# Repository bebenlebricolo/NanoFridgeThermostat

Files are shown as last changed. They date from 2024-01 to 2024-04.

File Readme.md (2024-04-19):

# Readme's Index
- [Readme's Index](#readmes-index)
- [Nano Fridge Thermostat](#nano-fridge-thermostat)
- [Nano Thermostat V2](#nano-thermostat-v2)
- [Known issues on V2 board](#known-issues-on-v2-board)
- [Git submodules setup (Optional, used for hardware development)](#git-submodules-setup-optional-used-for-hardware-development)
  - [Screenshots (view taken before manufacturing)](#screenshots-view-taken-before-manufacturing)
- [Hardware design](#hardware-design)
  - [Simulations](#simulations)
  - [Electronic design](#electronic-design)
    - [Mother board](#mother-board)
    - [Daughter board (AC power board)](#daughter-board-ac-power-board)
  - [Tools](#tools)
    - [Thermistor data source files generator](#thermistor-data-source-files-generator)
    - [Resistor bridge calculator](#resistor-bridge-calculator)
- [Tests](#tests)
  - [Building the tests](#building-the-tests)
  - [Tests dependencies](#tests-dependencies)
- [Acknowledgment](#acknowledgment)

# Nano Fridge Thermostat
Welcome to the Nano Fridge project !
This project started up because my fridge thermostat was dying (actually it was pretty dead and noticed the fridge was not cooling anymore) and I needed to find something very quickly in order to keep it running a bit longer.
It's aimed at replacing the cheap (but very reliable) thermomechanical switch that's used in most low-end fridges.

The very first revision operated on an Arduino Nano and used regular relays to perform its task.
It was essentially an Open-Loop system, running the compressor for 1 hour, and letting it rest for 2 hours.
This Open Loop process works fine but does not take into account the internal temperature of the fridge.
Hence, the actual temperature was oscillating a lot between 2 or 3°C and 6 to 8°C, depending on how many times we would open it.

The first revision of this project can be found on tag V1.0.0

# Nano Thermostat V2
A newer revision of the thermostat is currently in the works and several small improvements will be provided :
* Safe compressor start up procedure
* Thermistor support (NTC)
* Closed-Loop control algorithms (very simple hysteresis at first)
* Screen and buttons to monitor and setup the fridge parameters from outside the fridge.

More details can be found in the [NanoThermostat-V2](NanoThermostat-V2) folder.

A custom PCB was designed for this board (as the electrical design became more and more crowded with components and functionalities).
It can be found under the [Hardware](Hardware/) folder, and I used KiCAD 7 to design the boards.

# Known issues on V2 board
This applies to the git tag **hardware-V2.0.0-to-fab**
* Swapped buttons (silkscreen is "right" but - button actually is on the right and + button is on the left)
  * We only need to rewire them correctly :smile:

# Git submodules setup (Optional, used for hardware development)
In order for this project to be usable (especially to get all the footprints here), you'll need to initialise and download git submodules.
This can be done like so :
```bash
git submodule update --init --recursive
```

## Screenshots (view taken before manufacturing)
<figure>
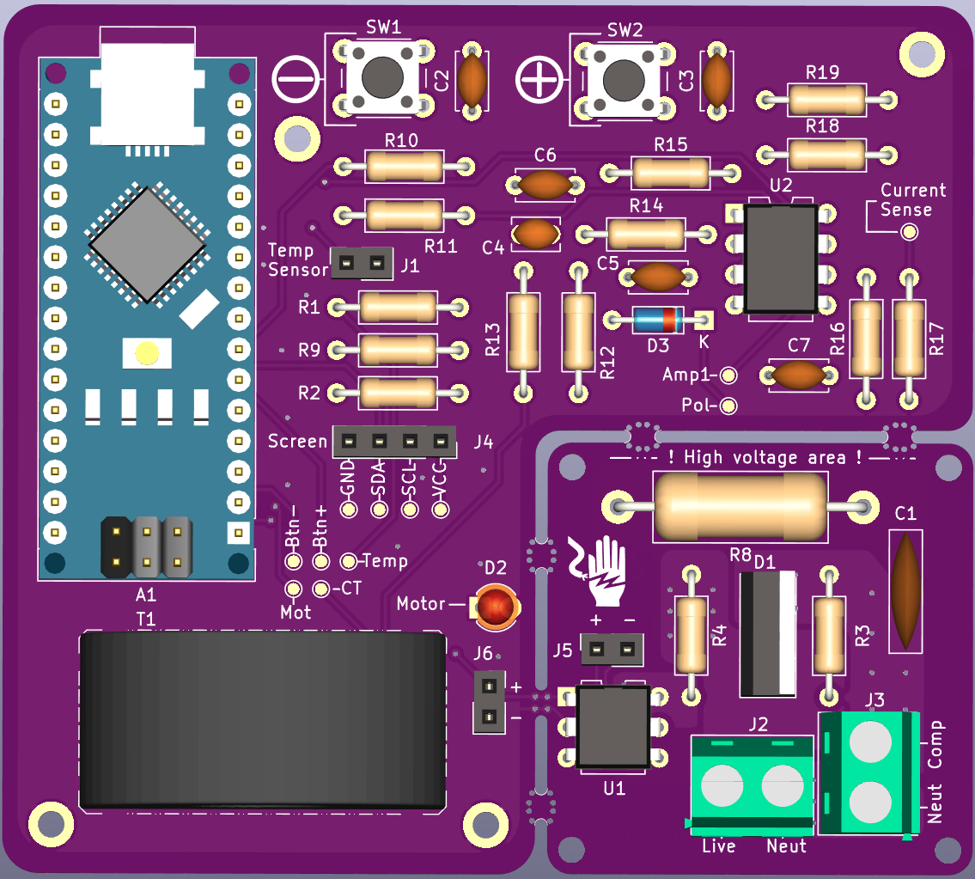
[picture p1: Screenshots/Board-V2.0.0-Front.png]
Board V2.0.0 Front
    
    <figcaption>Board V2.0.0, Front</figcaption>
</figure>
<figure>
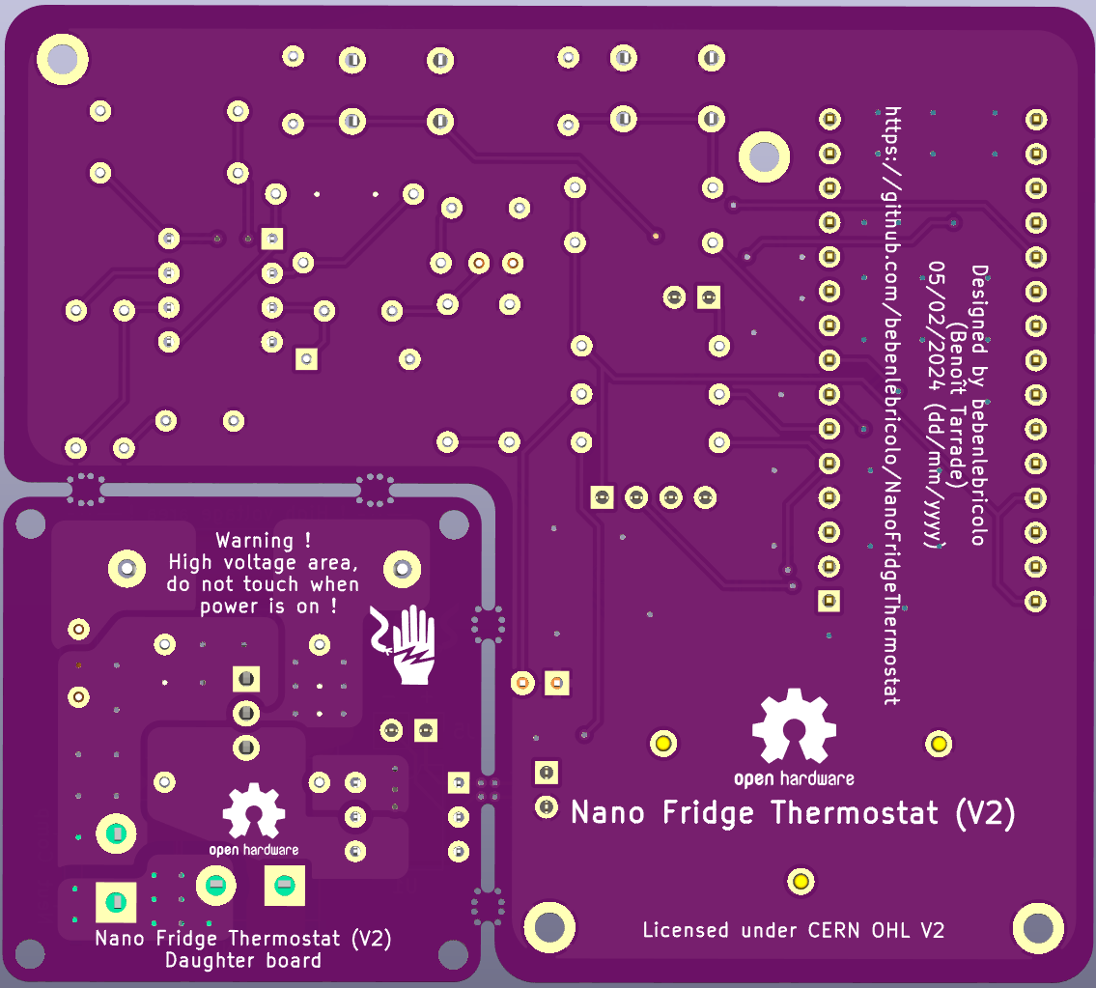
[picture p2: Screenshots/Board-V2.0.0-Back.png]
Board V2.0.0 Back
    
    <figcaption>Board V2.0.0, Back</figcaption>
</figure>
<figure>
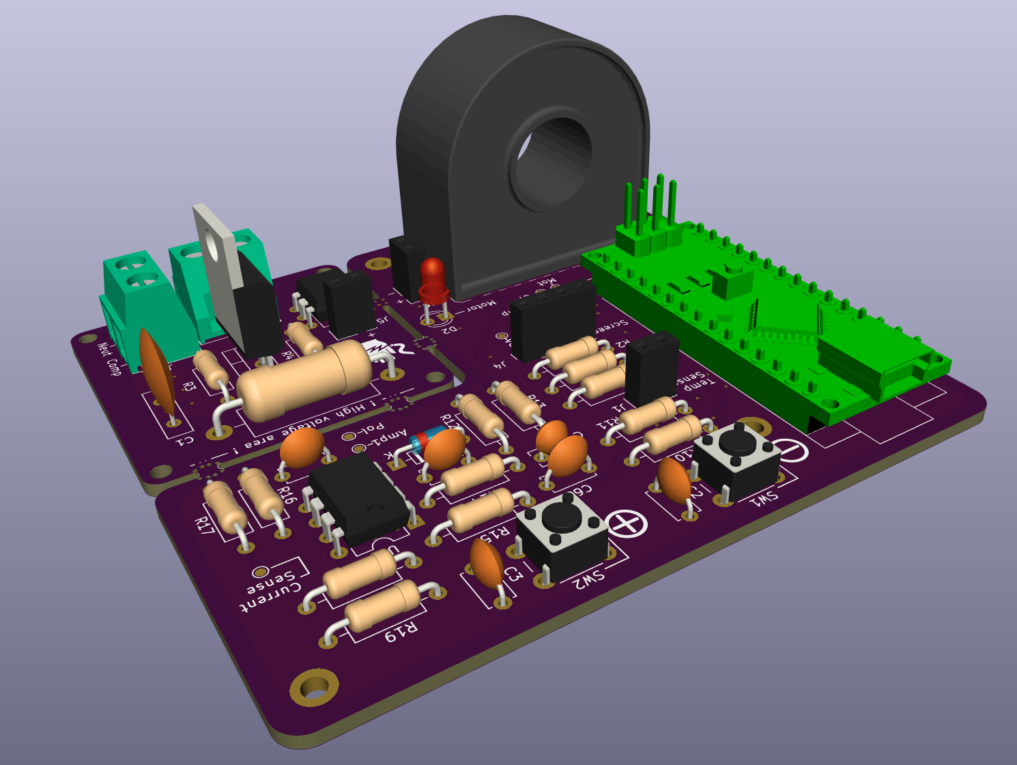
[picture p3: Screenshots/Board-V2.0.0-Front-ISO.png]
Board V2.0.0 Iso
    
    <figcaption>Board V2.0.0, Iso</figcaption>
</figure>

# Hardware design
As said, these boards were designed with KiCAD 7 which is a free open source software.
You'll need a copy of it installed on your machine in order to open hardware files.

## Simulations
Some simulations were used in this project as well and can be found under [Hardware/Simulations](Hardware/Simulations/).
Those simulations were performed with the very good LTSpice tool, released publicly and for free by Linear Technologies.
Despite not being open source per se, this tool can be installed on Linux as well using Wine wrappers.

## Electronic design
This new board (V2.0.0) includes 2 boards attached by small tabs. One of them carries the signal that goes to the triac driver. They are designed to be manually snapped, as the daughter board (the smaller one) needs to be galvanically isolated from the mother board.

### Mother board
The mother board carries and Arduino Nano V3 and works with low voltages (5V).
Power is supplied via the Arduino's USB connector and the system is designed to consume very little power (less than 100mA, most probably around 30/50 mA)

It's main features are :
* AC current sense : used to sense the current that goes into the fridge compressor
  * Used mainly as a security feature as it allows to detect conditions where the fridge compressor is stalled (when power cycling the compressor in time interval shorter than around 5 minutes, cooling fluids prevent the motor to start, hence pulling a large amount of current for an extended period of time, causing coil overheating).
  * This security feature is mostly intended to cover the cases where general power is cut off and quickly returns to normal. Microcontroller will reboot under such conditions and as there is no embedded RTC, there is no means to tell how long the power cut was, potentially causing the board to trigger the motor again. Monitoring pulled current can help detect such conditions and allow to delay compressor operation enough to get back under normal working conditions.
* Fridge compressor control using zero crossing detection (triac driver + triac)
* Fridge temperature sensing using NTC thermistor.
* I2C connector so that we can extend the board functionalities by plugging in a LCD screen.
* 2 buttons to control the boards behavior (forecasted roles were + and - buttons to lower or raise set point temperature, and reset internal memory.)

> Note : this board can easily be leveraged to control other small AC appliances ; as long as the triac is adapted to the target's power requirements. One will need to also adapt the 2 stages amplifier for the current sensing return loop in order to adapt to larger currents (and potentially adapt the Current Transformer as well).

### Daughter board (AC power board)
This small board can be detached from the mother board using the provided "mouse bites".
Usually, this board will be placed close to the compressor, in a well ventilated area to accommodate for the triac's heat under working conditions, whereas the mother board will be placed further.

It carries the triac driver (which is optoisolated) and the triac itself ([FT0814MH](https://docs.rs-online.com/2b24/0900766b8150e268.pdf), which is actually a Fagor specific item, specially crafted for fridges).
It's main role is then to switch the power on and off of the fridge's compressor.

## Tools
### Thermistor data source files generator
This repository embeds a small python ([thermistor_generator.py](Tools/thermistor_generator.py)) script whose purpose is to generate C source files for a given thermistor. It uses the basic parameters for a NTC thermistor :
* R0 : base resistance of the thermistor, at room temperature (usually, 25°Celsius)
* Beta constant : temperature constant, rated in Kelvin, for this thermistor
* name of the generated source files

It generates the default profile for an NTC thermistor, which needs to be compiled in the project in order to be used.
It's used through the small [thermistor.h](NanoThermostat-V2/thermistor.h) and [thermistor.c](NanoThermostat-V2/thermistor.c) module as the reference table for temperature reading.

Usage :
```bash
python thermistor_generator.py 100 3950 thermistor_ntc_100k_3950K --min -24 --max 25 --count 25
# 1 - Generating thermistor data
# 2 - Generating header file
# 3 - Generating source file
```
This generates files in the [Generated](Generated) folder.

### Resistor bridge calculator
This small python script ([resistor_bridge.py](Tools/resistor_bridge.py)) lets you calculate the ideal value for the upper resistor for a resistor bridge where a NTC thermistor is used as the lower part.
It finds the ideal value that maximizes the output voltage swing amplitude, based on the thermistor used temperature/resistance range.
Boosting the output voltage swing amplitude means that the Arduino's ADC will get a better resolution, hence better result as the usable voltage range is bigger.

Usage :
```bash
python resistor_bridge.py 100 1024
Ideal resistance value for R should be : 320.0
The unit (Ohms, KOhms, MOhms) is the same as input data
```

# Tests
This project embeds some tests projects.
Those tests are checking that the logic works on a desktop environment prior to be compiled and embedded on a tiny MCU.

## Building the tests
Runs with CMake :
```bash
cmake NanoThermostat-V2 -Bbuild
cd build/
make -j
```

## Tests dependencies
Googletest framework is used as a test framework and needs to be installed beforehand.
This is automatically done on Windows platforms (latest build zip is downloaded by CMake itself).
On Linux, a system-wide installation works very well :
```bash
pacman -S gtest # arch linux
apt-get install libgtest # Ubuntu/debian
```

# Acknowledgment
This repository uses open source software, tools and assets publicly available.

* [KiCAD](https://www.kicad.org/) 7.X
  * Used to develop the hardware/electronic design
* [FreeCAD](https://www.freecad.org/) 0.2XXX
* Used to develop the hardware/mechanical design
* [LTSpiceXVII](https://www.analog.com/en/resources/design-tools-and-calculators/ltspice-simulator.html) -> Available on Windows and Linux (via Wine, check your linux distribution packages).
  * Used to develop electronic simulations
* [kicad-lib-arduino](https://github.com/g200kg/kicad-lib-arduino)
  * Used as part of the hardware design process (mainly the Arduino Nano V3 3D model)
  * [Creative Common License : CC0 1.0 Universal](https://github.com/g200kg/kicad-lib-arduino/blob/main/LICENSE)
* [Panelization.pretty](https://github.com/madworm/Panelization.pretty)
  * Used as part of the hardware design process (used the mouse bites footprints)
  * No license for now (Feb 2024) ?
* [googletest](https://github.com/google/googletest)
  * Google's C/C++ unit testing framework
  * [BSD-3-Clause license](https://github.com/google/googletest/blob/main/LICENSE)

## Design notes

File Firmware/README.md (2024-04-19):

# Index
- [Index](#index)
- [NanoFridgeThermostat V2](#nanofridgethermostat-v2)
- [Hardware specs (first iteration)](#hardware-specs-first-iteration)
- [Safety features](#safety-features)
    - [Automatic rerun protection](#automatic-rerun-protection)
    - [Safe boot up sequence](#safe-boot-up-sequence)
    - [Temperature trigger Hysteresis (No PID)](#temperature-trigger-hysteresis-no-pid)
- [Roadmap](#roadmap)
  - [V2.0](#v20)
  - [V2.1](#v21)
  - [V2.2](#v22)
  - [V3 and Onwards](#v3-and-onwards)

# NanoFridgeThermostat V2
Off-the-shelf fridge thermostat using an ArduinoNano to replace a broken fridge thermomechanical thermostat.

This project was born with the sole purpose of repairing a dying fridge whose thermostat was completely dead.
The idea is first to provide a very basic cooling support, with a simple on/off cycle that can be programmed using on seconds and off seconds.

# Hardware specs (first iteration)
* Solid state switching circuitry
  * Optoisolated triac driver circuit (MOC3042 -> withstands 400V peak)
  * 600V / 8A RMS Triac (FT0814MH TU) -> TO220 package
* NTC Thermistor [amazon link](https://www.amazon.fr/gp/product/B07CQT5S7Y/ref=ppx_yo_dt_b_asin_title_o00_s00?ie=UTF8&psc=1)
  * Advertised  as 100k @ 25°C
  * Upper bridge resistor of 330kOhms gives the maximum output voltage swing from the divider bridge configuration (see [Thermistor spreadsheet](Thermistor%20values.ods) for a more detailed view).
* Phone USB charger (5V), 230V AC -> 5V DC
  * Ideally this could be replaced by a standalone AC/DC converter in the system, but for now a simple phone charger bloc will do the trick.

# Safety features
### Automatic rerun protection
As fridges' thermodynamic cycle has some constraints, it's not possible to restart the motor right after a run for a short period of time.
My fridge is equipped with a fail-safe circuitry that breaks the circuit whenever the motor is stalled. A stalled motor draws much more current than expected in normal use, and it makes a thermal circuit breaker heat up, until the contact points separate ; the arm cools down and after some time springs back in normal position and closes the circuit again.

I don't want to rely only on this safety feature, so I'll add a software timer in between motor start up so that I'm sure it's not started in a too short amount of time.

### Safe boot up sequence
When the system boots up, it'll wait for 5 seconds before starting normal operation.
This will allow for the user to enter the "learn" mode (with a long press on a button).
This mode will be used to reset internal memory and start characterising compressor motor again (monitoring current in "normal" operation).
This characterisation of the motor will be later used to detect stalled motor conditions even if the system's power goes off for a while and returns back in a short time.
Motor characterisation loop runs the compressor regardless of the frige's temperature in order to provide consistent results.

Then, normal operation will take over.
A long press on the same button allows to enter the learning mode again.
If the board was already in cooling mode at this time, it'll simply keep running the motor until the end of the learn process and reverts back to operation without interfering with the current operation.

### Temperature trigger Hysteresis (No PID)
I'll use an Hysteresis instead of a PID trigger for now and keep track of the ON/OFF cycles, avoiding to start the motor too often.
The risk when starting the motor too often (as stated above) is to go into thermal runaway or to stress the motor and compressor too much with start up cycles.
This can be minimized by opening a window that relies on a hysteresis.
PID will do the trick as well, the hysteresis function is more than sufficient to keep hovering around the average temperature whilst keeping the startup cycles at a minimum.

# Roadmap
## V2.0
* Fixed 4.0 °C degrees temperature target, no UI (no screen, no buttons, no interactions)
* Fixed hysteresis window (+- 2°C around the set point)
* Start up protection delay (as mentioned in [Automatic rerun protection](#automatic-rerun-protection))

## V2.1
* Flexible target temperature (dynamically adjustable). Requires some level of human interaction
  * I2C Oled screen with buttons
    * "+" and "-" buttons
    * One "Ok" button

## V2.2
* Probably a PID

## V3 and Onwards
* Additional light control (LEDs)
* Fans to circulate the air within the fridge
* Custom PCB that hosts all of the features described above

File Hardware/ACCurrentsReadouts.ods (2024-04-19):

Current (ma)
-160
-160
-140
-110
-80
-20
30
70
110
140
160
160
140
120
80
30
-30
-70
-110
-140
 | Gain
 | 22
Voltage (mv) | Calculated current | Max | Min | Peak-Peak | RMS
293 | 133 | 194,090909090909 | -191,818181818182 | 385,909090909091 | 136,439467551677
365 | 166
427 | 194
413 | 188
374 | 170
302 | 137
206 | 94
62 | 28
-72 | -33
-192 | -87
-283 | -129
-379 | -172
-422 | -192
-418 | -190
-365 | -166
-307 | -140
-206 | -94
-77 | -35
77 | 35
182 | 83

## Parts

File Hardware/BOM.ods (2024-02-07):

Source:
Date: | lun. 05 févr. 2024 21:03:38
Tool: | Eeschema 7.0.10
Generator: | /usr/share/kicad/plugins/bom_csv_grouped_by_value.py
Component Count: | 57
Collated Components:
Item | Qty | Reference(s) | Value | Ref | LibPart | Footprint | Datasheet | DNP
1 | 1 | A1 | Arduino_Nano_v3.x | Arduino Nano V3 | MCU_Module:Arduino_Nano_v3.x | Module:Arduino_Nano | http://www.mouser.com/pdfdocs/Gravitech_Arduino_Nano3_0.pdf
2 | 1 | C1 | 10n / 500V+ AC | C322C103KBR5TA | Device:C | Capacitor_THT:C_Disc_D10.0mm_W2.5mm_P5.00mm | ~
3 | 5 | C2, C3, C5, C6, C7 | 1u | RCER71H105K2M1H03A | Device:C | Capacitor_THT:C_Disc_D4.7mm_W2.5mm_P5.00mm | ~
4 | 1 | C4 | 100n | K104K15X7RF53L2 | Device:C | Capacitor_THT:C_Disc_D3.8mm_W2.6mm_P2.50mm | https://docs.rs-online.com/b86a/0900766b816adfc3.pdf
5 | 1 | D1 | FT0814MH | FT0814MH | Device:Q_TRIAC_A1A2G | Package_TO_SOT_THT:TO-220-3_Vertical | https://docs.rs-online.com/2b24/0900766b8150e268.pdf
6 | 1 | D2 | LED | Any 3mm Led will do | Device:LED | LED_THT:LED_D3.0mm | ~
7 | 1 | D3 | D_Zener | BZX79-C5V1,113 | Device:D_Zener | Diode_THT:D_DO-35_SOD27_P7.62mm_Horizontal | ~
10 | 1 | J1 | ConnectorTriacDriver1 | Soldering pad (or 2.54 pitch header) | Connector:Conn_01x02_Socket | Connector_PinSocket_2.54mm:PinSocket_1x02_P2.54mm_Vertical | ~
11 | 1 | J5 | ConnectorTriacDriver2 | Soldering pad (or 2.54 pitch header) | Connector:Conn_01x02_Socket | Connector_PinSocket_2.54mm:PinSocket_1x02_P2.54mm_Vertical | ~
12 | 1 | J2 | Main_Connector | TE-282836-2 | Connector:Conn_01x02_Socket | TEConnectors:TE-282836-2-5.08mm | https://docs.rs-online.com/6880/0900766b8002dc8a.pdf
13 | 1 | J3 | CompressorMotor_Connector | TE-282836-2 | Connector:Conn_01x02_Socket | TEConnectors:TE-282836-2-5.08mm | https://docs.rs-online.com/6880/0900766b8002dc8a.pdf
14 | 1 | J4 | I2C_Conn | Soldering pad (or 2.54 pitch header) | Connector:Conn_01x04_Socket | Connector_PinSocket_2.54mm:PinSocket_1x04_P2.54mm_Vertical | ~
15 | 1 | R1 | 330K | 1/4 Watt through hole resistor (10%) | Device:R | Resistor_THT:R_Axial_DIN0207_L6.3mm_D2.5mm_P10.16mm_Horizontal | ~
16 | 3 | R2, R3, R9 | 330 | 1/4 Watt through hole resistor (10%) | Device:R | Resistor_THT:R_Axial_DIN0207_L6.3mm_D2.5mm_P10.16mm_Horizontal | ~
17 | 1 | R4 | 360 | 1/4 Watt through hole resistor (10%) | Device:R | Resistor_THT:R_Axial_DIN0207_L6.3mm_D2.5mm_P10.16mm_Horizontal | ~
18 | 1 | R8 | 330Ω / 1W | CFR200J330R | Device:R | Resistor_THT:R_Axial_DIN0614_L14.3mm_D5.7mm_P20.32mm_Horizontal | ~
19 | 2 | R10, R11 | 1k | 1/4 Watt through hole resistor (10%) | Device:R | Resistor_THT:R_Axial_DIN0207_L6.3mm_D2.5mm_P10.16mm_Horizontal | ~
20 | 1 | R12 | 22k | 1/4 Watt through hole resistor (10%) | Device:R | Resistor_THT:R_Axial_DIN0207_L6.3mm_D2.5mm_P10.16mm_Horizontal | ~
21 | 1 | R13 | 100 / 0,25W | 1/4 Watt through hole resistor (10%) | Device:R | Resistor_THT:R_Axial_DIN0207_L6.3mm_D2.5mm_P10.16mm_Horizontal | ~
22 | 1 | R14 | 2.2k | 1/4 Watt through hole resistor (10%) | Device:R | Resistor_THT:R_Axial_DIN0207_L6.3mm_D2.5mm_P10.16mm_Horizontal | ~
23 | 4 | R15, R17, R18, R19 | 100k | 1/4 Watt through hole resistor (10%) | Device:R | Resistor_THT:R_Axial_DIN0207_L6.3mm_D2.5mm_P10.16mm_Horizontal | ~
24 | 1 | R16 | 10k | 1/4 Watt through hole resistor (10%) | Device:R | Resistor_THT:R_Axial_DIN0207_L6.3mm_D2.5mm_P10.16mm_Horizontal | ~
25 | 2 | SW1, SW2 | SW_Push | Generic 6mm switch | Switch:SW_Push | Button_Switch_THT:SW_PUSH_6mm | ~
26 | 1 | T1 | CST1 | RS Pro : 124-3888 | CurrentTransformers:CT-RSPRO-1243888 | CurrentTransformer:CT-RSPRO-1243888 | https://docs.rs-online.com/3a8a/0900766b8169af75.pdf
27 | 1 | U1 | MOC3042M | MOC3042M (DIP-6 format) | Relay_SolidState:MOC3042M | Package_DIP:DIP-6_W7.62mm | https://www.onsemi.com/pub/Collateral/MOC3043M-D.pdf
28 | 1 | U2 | TL072 | TL072CD (DIP-8 format) | Amplifier_Operational:TL072 | Package_DIP:DIP-8_W7.62mm | http://www.ti.com/lit/ds/symlink/tl071.pdf

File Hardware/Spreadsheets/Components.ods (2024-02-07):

Snubber capacitor
Ref | Brand | Price (€) | Link | datasheet
C322C103KBR5TA | KEMET | 0,95 | https://fr.rs-online.com/web/p/condensateurs-ceramique-multicouches/9060654 | https://docs.rs-online.com/f300/0900766b81706bea.pdf
Snubber resistor
CFR200J330R | TE Connectivity | 0,12 | https://fr.rs-online.com/web/p/resistances-traversantes/0131996
Current transformer
124-3888 | RS-PRO | 1,99 | https://fr.rs-online.com/web/p/transformateurs-de-courant/1243888 | https://docs.rs-online.com/3a8a/0900766b8169af75.pdf
Low voltage cap
Ref | cap | voltage rating | Brand | Price (€) | Link | datasheet
K104K15X7RF53L2 | 100nF | 50V | Vishay | 0,119 | https://fr.rs-online.com/web/p/condensateurs-ceramique-multicouches/1816552 | https://docs.rs-online.com/b86a/0900766b816adfc3.pdf
RCER71H105K2M1H03A | 1uF | 50V | Murata | 0,355 | https://fr.rs-online.com/web/p/condensateurs-ceramique-multicouches/8410755 | https://docs.rs-online.com/dd62/0900766b8135e0d4.pdf
Zener 5.1V | Power | Price (€) | Link | datasheet
1N5338BG | 5W | 0,44 | https://fr.rs-online.com/web/p/diodes-zener/0463274 | https://docs.rs-online.com/b551/0900766b814f4429.pdf
BZX79-C5V1,113 | 500mW | 0,175 | https://fr.rs-online.com/web/p/diodes-zener/5443597 | https://docs.rs-online.com/9271/0900766b8073397e.pdf
Bornier 2 contacts
Ref | Brand | Price (€) | Link | datasheet
282836-2 | TE Connectivity | 1,26 | https://fr.rs-online.com/web/p/borniers-pour-circuits-imprimes/3617667 | https://docs.rs-online.com/6880/0900766b8002dc8a.pdf

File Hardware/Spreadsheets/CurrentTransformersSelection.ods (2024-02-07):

Current Transformers for 50/60Hz monitoring
Price (With taxes) € | Turns ratio | Rated Amps | Burden resistor | Link | Manufacturer | Datasheet
4,42 | « 1000:1 » | 10 | 10 | https://fr.rs-online.com/web/p/transformateurs-de-courant/1243903 | RS Pro | https://docs.rs-online.com/8008/0900766b81537b7e.pdf
4,42 | « 750:1 » | 7,5 | 100 | https://fr.rs-online.com/web/p/transformateurs-de-courant/1243899 | RS Pro | https://docs.rs-online.com/4c18/0900766b81537b7a.pdf
1,99 | « 1000:1 » | 75 | 100 | https://fr.rs-online.com/web/p/transformateurs-de-courant/1243888 | RS Pro | https://docs.rs-online.com/3a8a/0900766b8169af75.pdf
1,99 | « 1000:1 » | 25 (max 75) | 100 | https://fr.rs-online.com/web/p/transformateurs-de-courant/1243888 | RS Pro | https://docs.rs-online.com/3a8a/0900766b8169af75.pdf
2,26 | « 1000:1 » | 40 | 100 | https://fr.rs-online.com/web/p/transformateurs-de-courant/5374536 | Nuvotem Talema (India) | https://docs.rs-online.com/d4c8/0900766b807760fd.pdf

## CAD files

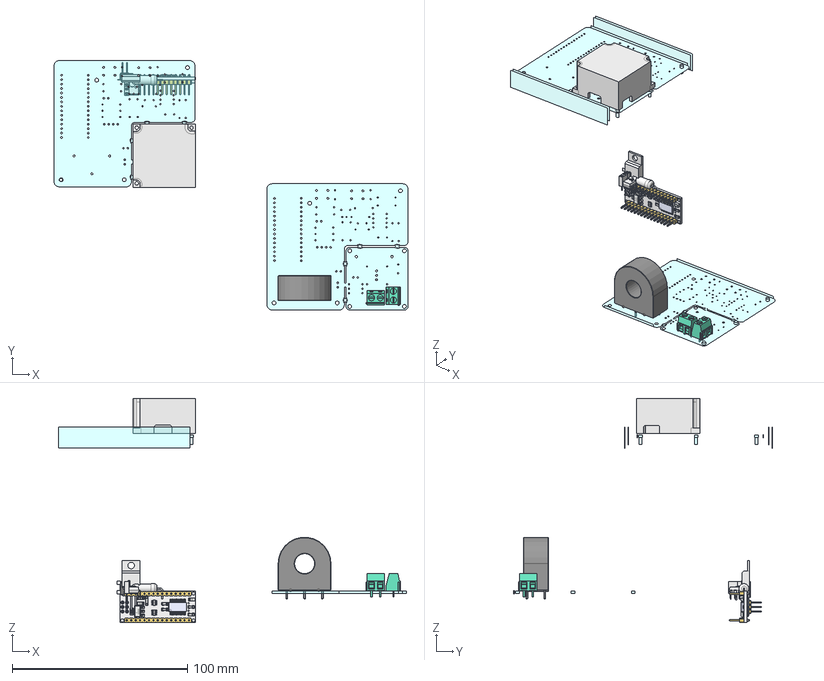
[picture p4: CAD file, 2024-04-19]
Hardware/Mechanical/board-V2.0.0-assembly_workbench.FCStd
202.0 x 147.3 x 128.1 mm
AcProtection
Element
Element001
Element002
Element003
Element004
Element005
Element006
Element007
Element010
Element011
Element012
Element013
R_Axial_DIN0207_L63mm_D25mm_P1016mm_Horizontal
C_Disc_D100mm_W25mm_P500mm
LED_D3.0mm
C_Disc_D47mm_W25mm_P500mm
R_Axial_DIN0207_L63mm_D25mm_P1016mm_Horizontal001
R_Axial_DIN0207_L63mm_D25mm_P1016mm_Horizontal002
PinSocket_1x02_P254mm_Vertical
R_Axial_DIN0207_L63mm_D25mm_P1016mm_Horizontal003
C_Disc_D47mm_W25mm_P500mm001
TO-220-3_Vertical
R_Axial_DIN0207_L63mm_D25mm_P1016mm_Horizontal004
R_Axial_DIN0207_L63mm_D25mm_P1016mm_Horizontal005
SW_PUSH_6mm
R_Axial_DIN0207_L63mm_D25mm_P1016mm_Horizontal006
PinSocket_1x04_P254mm_Vertical
PinSocket_1x02_P254mm_Vertical001
C_Disc_D47mm_W25mm_P500mm002
C_Disc_D38mm_W26mm_P250mm
R_Axial_DIN0207_L63mm_D25mm_P1016mm_Horizontal007
D_DO-35_SOD27_P7.62mm_Horizontal
D_DO-35_SOD27_P7.62mm_Horizontal001
C_Disc_D47mm_W25mm_P500mm003
C_Disc_D47mm_W25mm_P500mm004
PinSocket_1x02_P254mm_Vertical002
R_Axial_DIN0207_L63mm_D25mm_P1016mm_Horizontal008
R_Axial_DIN0207_L63mm_D25mm_P1016mm_Horizontal009
DIP-6_W7.62mm
R_Axial_DIN0207_L63mm_D25mm_P1016mm_Horizontal010
R_Axial_DIN0207_L63mm_D25mm_P1016mm_Horizontal011
R_Axial_DIN0207_L63mm_D25mm_P1016mm_Horizontal012
R_Axial_DIN0614_L143mm_D57mm_P2032mm_Horizontal
R_Axial_DIN0207_L63mm_D25mm_P1016mm_Horizontal013
DIP-8_W7.62mm
SW_PUSH_6mm002
R_Axial_DIN0207_L63mm_D25mm_P1016mm_Horizontal014
C-282836-2
C-282836-003
nano-board
2pin_header__02
2pin_header__003
2pin_header__004
15pin_header__
15pin_header__001
atmega328
ftdi FT232rl
smt_resistor222
smt_resistor223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

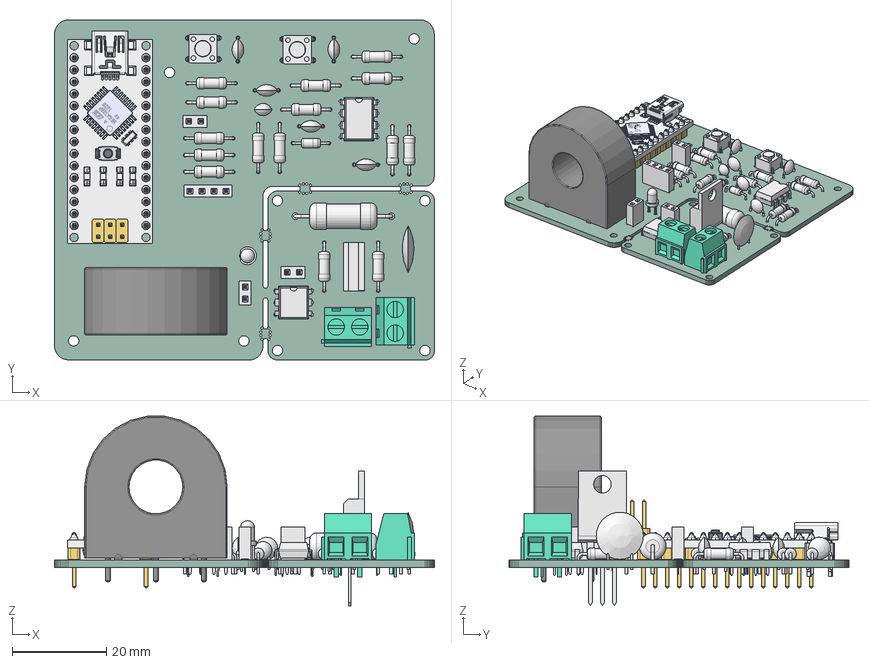
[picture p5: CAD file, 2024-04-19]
Hardware/Mechanical/board-V2.0.0-assembly.FCStd
80.5 x 72.1 x 40.2 mm
R_Axial_DIN0207_L63mm_D25mm_P1016mm_Horizontal
C_Disc_D100mm_W25mm_P500mm
LED_D3.0mm
C_Disc_D47mm_W25mm_P500mm
R_Axial_DIN0207_L63mm_D25mm_P1016mm_Horizontal001
R_Axial_DIN0207_L63mm_D25mm_P1016mm_Horizontal002
PinSocket_1x02_P254mm_Vertical
R_Axial_DIN0207_L63mm_D25mm_P1016mm_Horizontal003
C_Disc_D47mm_W25mm_P500mm001
TO-220-3_Vertical
R_Axial_DIN0207_L63mm_D25mm_P1016mm_Horizontal004
R_Axial_DIN0207_L63mm_D25mm_P1016mm_Horizontal005
SW_PUSH_6mm
R_Axial_DIN0207_L63mm_D25mm_P1016mm_Horizontal006
PinSocket_1x04_P254mm_Vertical
PinSocket_1x02_P254mm_Vertical001
C_Disc_D47mm_W25mm_P500mm002
C_Disc_D38mm_W26mm_P250mm
R_Axial_DIN0207_L63mm_D25mm_P1016mm_Horizontal007
D_DO-35_SOD27_P7.62mm_Horizontal
D_DO-35_SOD27_P7.62mm_Horizontal001
C_Disc_D47mm_W25mm_P500mm003
C_Disc_D47mm_W25mm_P500mm004
PinSocket_1x02_P254mm_Vertical002
R_Axial_DIN0207_L63mm_D25mm_P1016mm_Horizontal008
R_Axial_DIN0207_L63mm_D25mm_P1016mm_Horizontal009
DIP-6_W7.62mm
R_Axial_DIN0207_L63mm_D25mm_P1016mm_Horizontal010
R_Axial_DIN0207_L63mm_D25mm_P1016mm_Horizontal011
R_Axial_DIN0207_L63mm_D25mm_P1016mm_Horizontal012
R_Axial_DIN0614_L143mm_D57mm_P2032mm_Horizontal
R_Axial_DIN0207_L63mm_D25mm_P1016mm_Horizontal013
DIP-8_W7.62mm
SW_PUSH_6mm002
R_Axial_DIN0207_L63mm_D25mm_P1016mm_Horizontal014
NanoFridgeThermistat-board PCB
C-282836-2
C-282836-003
nano-board
2pin_header__02
2pin_header__003
2pin_header__004
15pin_header__
15pin_header__001
atmega328
ftdi FT232rl
smt_resistor222
smt_resistor223
smt_resistor224
smt_resistor225
smt_resistor226
led
led001
led003
led004
led006
led007
led009
led010
16mhz crystal - measured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

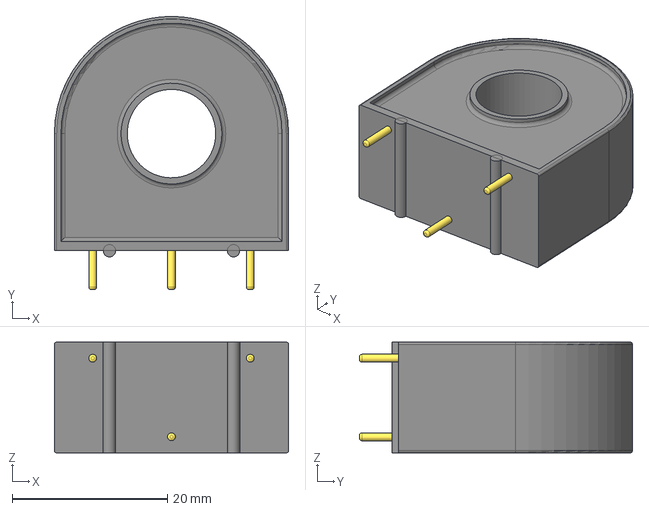
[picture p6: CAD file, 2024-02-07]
Hardware/NanoFridgeThermistat-board/3D/RS-PRO 1243888 Current Transformer-Body.step
30.2 x 35.2 x 14.3 mm

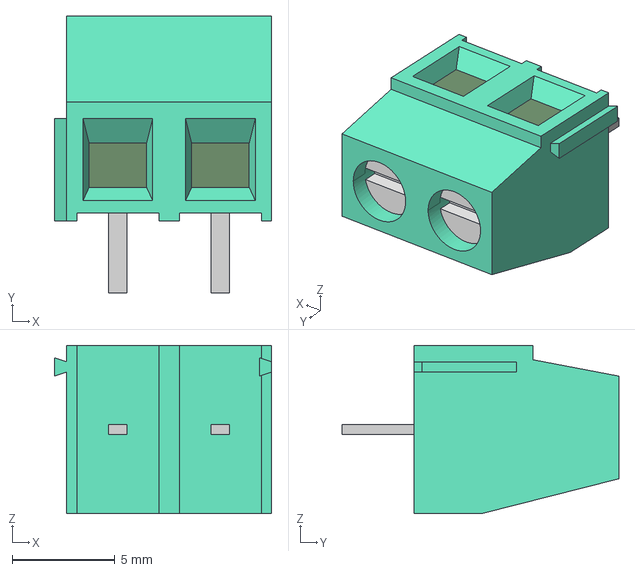
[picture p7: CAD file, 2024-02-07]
Hardware/NanoFridgeThermistat-board/3D/TE-Connectivity-282836-2-C-282836-2.step
10.6 x 13.5 x 8.20 mm

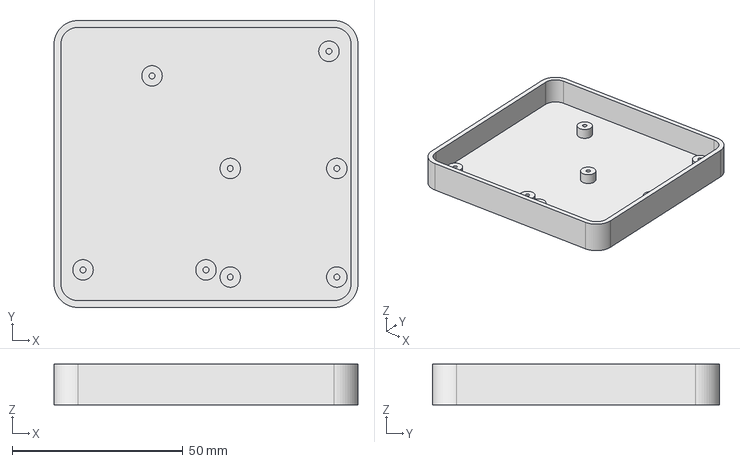
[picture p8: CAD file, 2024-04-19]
Hardware/Mechanical/BottomCase.step
89.0 x 84.0 x 12.0 mm

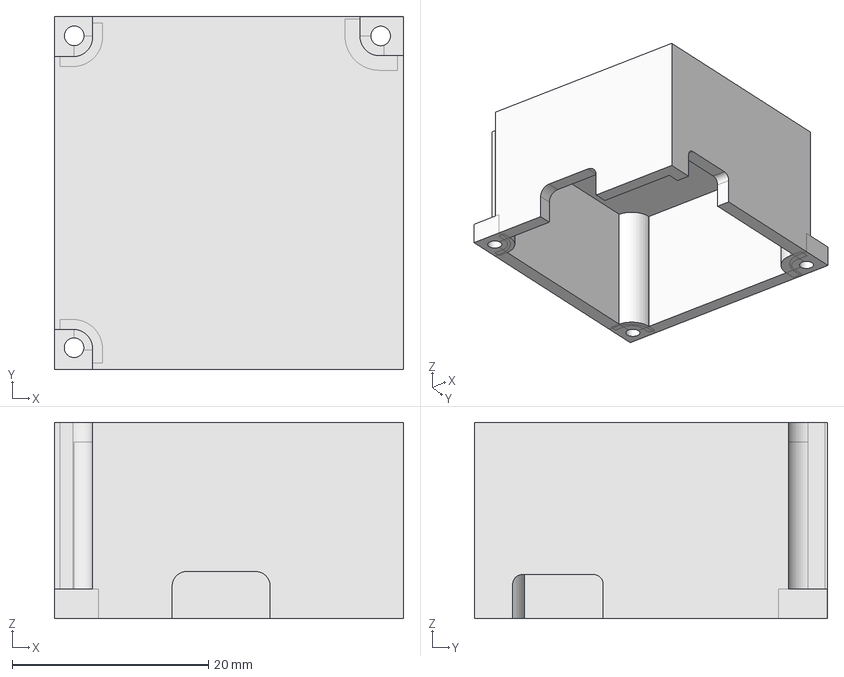
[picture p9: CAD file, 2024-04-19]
Hardware/Mechanical/ACProtection.step
35.6 x 36.0 x 20.0 mm

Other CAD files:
Hardware/Mechanical/board-V2.0.0-assembly_workbench_parts/arduino nano_parts/MINIUSB - MEASURED.fcstd
Hardware/Mechanical/board-V2.0.0-assembly_workbench_parts/NanoFridgeThermistat-board 1.fcstd
Hardware/Mechanical/board-V2.0.0-assembly_workbench_parts/NanoFridgeThermistat-board 1_parts/D_DO-35_SOD27_P7.62mm_Horizontal003_parts/D_DO-35_SOD27_P7.62mm_Horizontal002.fcstd
Hardware/Mechanical/board-V2.0.0-assembly_workbench_parts/NanoFridgeThermistat-board 1_parts/R_Axial_DIN0207_L6.3mm_D2.5mm_P10.16mm_Horizontal012.fcstd
Hardware/Mechanical/board-V2.0.0-assembly_workbench_parts/arduino nano.fcstd
Hardware/Mechanical/board-V2.0.0-assembly_workbench_parts/arduino nano_parts/led002.fcstd
Hardware/Mechanical/board-V2.0.0-assembly_workbench_parts/NanoFridgeThermistat-board 1_parts/PinSocket_1x04_P2.54mm_Vertical.fcstd
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

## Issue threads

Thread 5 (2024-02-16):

[Current Measure] : implement proper testing for the current RMS measurements

bebenlebricolo, 2024-02-16:
Now current measurements is implemented in a naïve way and is not tested yet.
In order to assert the maths are working out on the RMS measurements, I'll need to test the code.
* Split the code of current readings in it's own file
* Perform RMS calculations with approximations (for a low power MCU such as Atmega328PB)
* Try with various sampling frequencies, assuming Main's supply frequency is 50 Hz.
* -> Check what's the minimum required sampling frequency in order to get a clean reading / calculation of avg current and RMS current.

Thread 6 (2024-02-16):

[Fast ADC] : Switch to a lower level ADC implementation with Async interfaces

bebenlebricolo, 2024-02-16:
Arduino analogRead takes a fair amount of time with maximum resolution.
In order to get faster readings, ADC can be triggered asynchronously.

Maybe a good opportunity to integrate AvrAsyncCore instead of Arduino Libs ?

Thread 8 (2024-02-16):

[UI/UX] : Implement UI with OLED screen (SSD1306 0.96")

bebenlebricolo, 2024-02-16:
This project needs a simple OLED screen to display stuff.
We need to display :
* Actual fridge temperature
* Temperature target (set point)
* Whether the compressor is running or not
* Stalled motor condition ?

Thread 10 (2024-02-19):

[Temperature Control] : Implement proper temperature control

bebenlebricolo, 2024-02-19:
Temperature control is key to properly control the fridge compressor.
A simple hysteresis might be used to match the targeted temperature.
Temp window can be +-2°C.

Prevent short cycles if possible; we'd like not to run the compressor on too short cycles to help reduce prematured wear.

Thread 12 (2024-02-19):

[LED] : Implement a small LED module that'll blink the LED with various behaviors

bebenlebricolo, 2024-02-19:
We need a way to control a LED with various displayed behaviors :
* ON
* OFF
* Short blink (3 On/Off then Off) -> Used to indicate the "Ok" feedback
   * Ok when config is written to EEPROM
* Soft "breathing" pattern -> Used to indicate that we are in the current learning phase
* Short pulses pattern -> Indicate that we are in a stalled motor condition and that we are waiting for the fluids pressure to equalize in the system.

-> Only relies on time (no interrupts, no PWM).
-> software based PWM for the breathing mode (f around 50Hz should be enough).

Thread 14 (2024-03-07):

[LED] : Make soft PWM faster !

bebenlebricolo, 2024-03-07:
At the moment, current version of LED PWM code can run at about 166Hz maximum.
Plus, we can clearly visually see the power grading increments of the LED's light.
Like for a target frequency of 200 Hz (which is an actual 166 Hz), we can see 4 color gradings and we can clearly feel the increments.

This happens because of the resolution of the timer (1 ms) and the various aliasing encountered in the code when the ramps are computed.

From the oscilloscope, I could see :
| steps | 0 | 1 |2 | 3 | 4 | 5 | 6 | 7 | 8 | 9 |
|-------|--|---|--|---|--|---|--|---|---|---|
| ms (on time) | 0 | 1 | 2 | 3| 3 | 3| 3 | 2 | 1 | 0 |
| power (%) | 0 | 20 | 40 | 60| 60 | 60 |60 | 40 | 20 | 0|

This is due to the fact that we are using Timer2 that is interrupted every milliseconds.
Plus, there is extra overhead in the curve generation and interpolation, even when it's not required.

I can do 2/3 things to improve that :
* Use timer1  instead (16 bits) and set the timer to run at 1MHz -> prescaler of 16.
   * Overflows at 999 which automatically counts the milliseconds
   * -> More precision (we can use higher frequencies and unlock kHz domains easily with plenty of resolution points (like 10-20)
* Use timer2 (8 bit) and set it to run at 1 MHz -> prescaler of 16 again
   * Overflows at 250 µs -> count up to 4 and increment millisecond
   * -> Custom handling of time, more complex
   * More precision (we can use microseconds and milliseconds parts in order to recompose higher frequencies artificially)
* Only compute the curve when the current step is incremented ( more explicitely, compute the duty cycle when we need it and store it until we change the step, so that we don't have to re-run the computations and interpolation at every cycle).

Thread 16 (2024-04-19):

[Flexibility] : Allow end user to totally remove the current reading pipeline

bebenlebricolo, 2024-04-19:
Some user won't need / want the current reading features and all the additional safety features coming from that.
It'll allow to build a stripped down version of the board where user won't need :
* Current transformer
* Dual stage amplifier
This will help cutting the bill down a little bit.

A simple(ish) solution would be to use :
```C
#ifndef USE_CURRENT_MONITORING_FEATURES
#define USE_CURRENT_MONITORING_FEATURES 1
#endif
```

This will disable whole code blocks and the running loop will get much simpler.
One can then simply manually override that in the source code or via the build tools ([like platformio .ini file](https://docs.platformio.org/en/latest/projectconf/sections/env/options/build/build_flags.html)).

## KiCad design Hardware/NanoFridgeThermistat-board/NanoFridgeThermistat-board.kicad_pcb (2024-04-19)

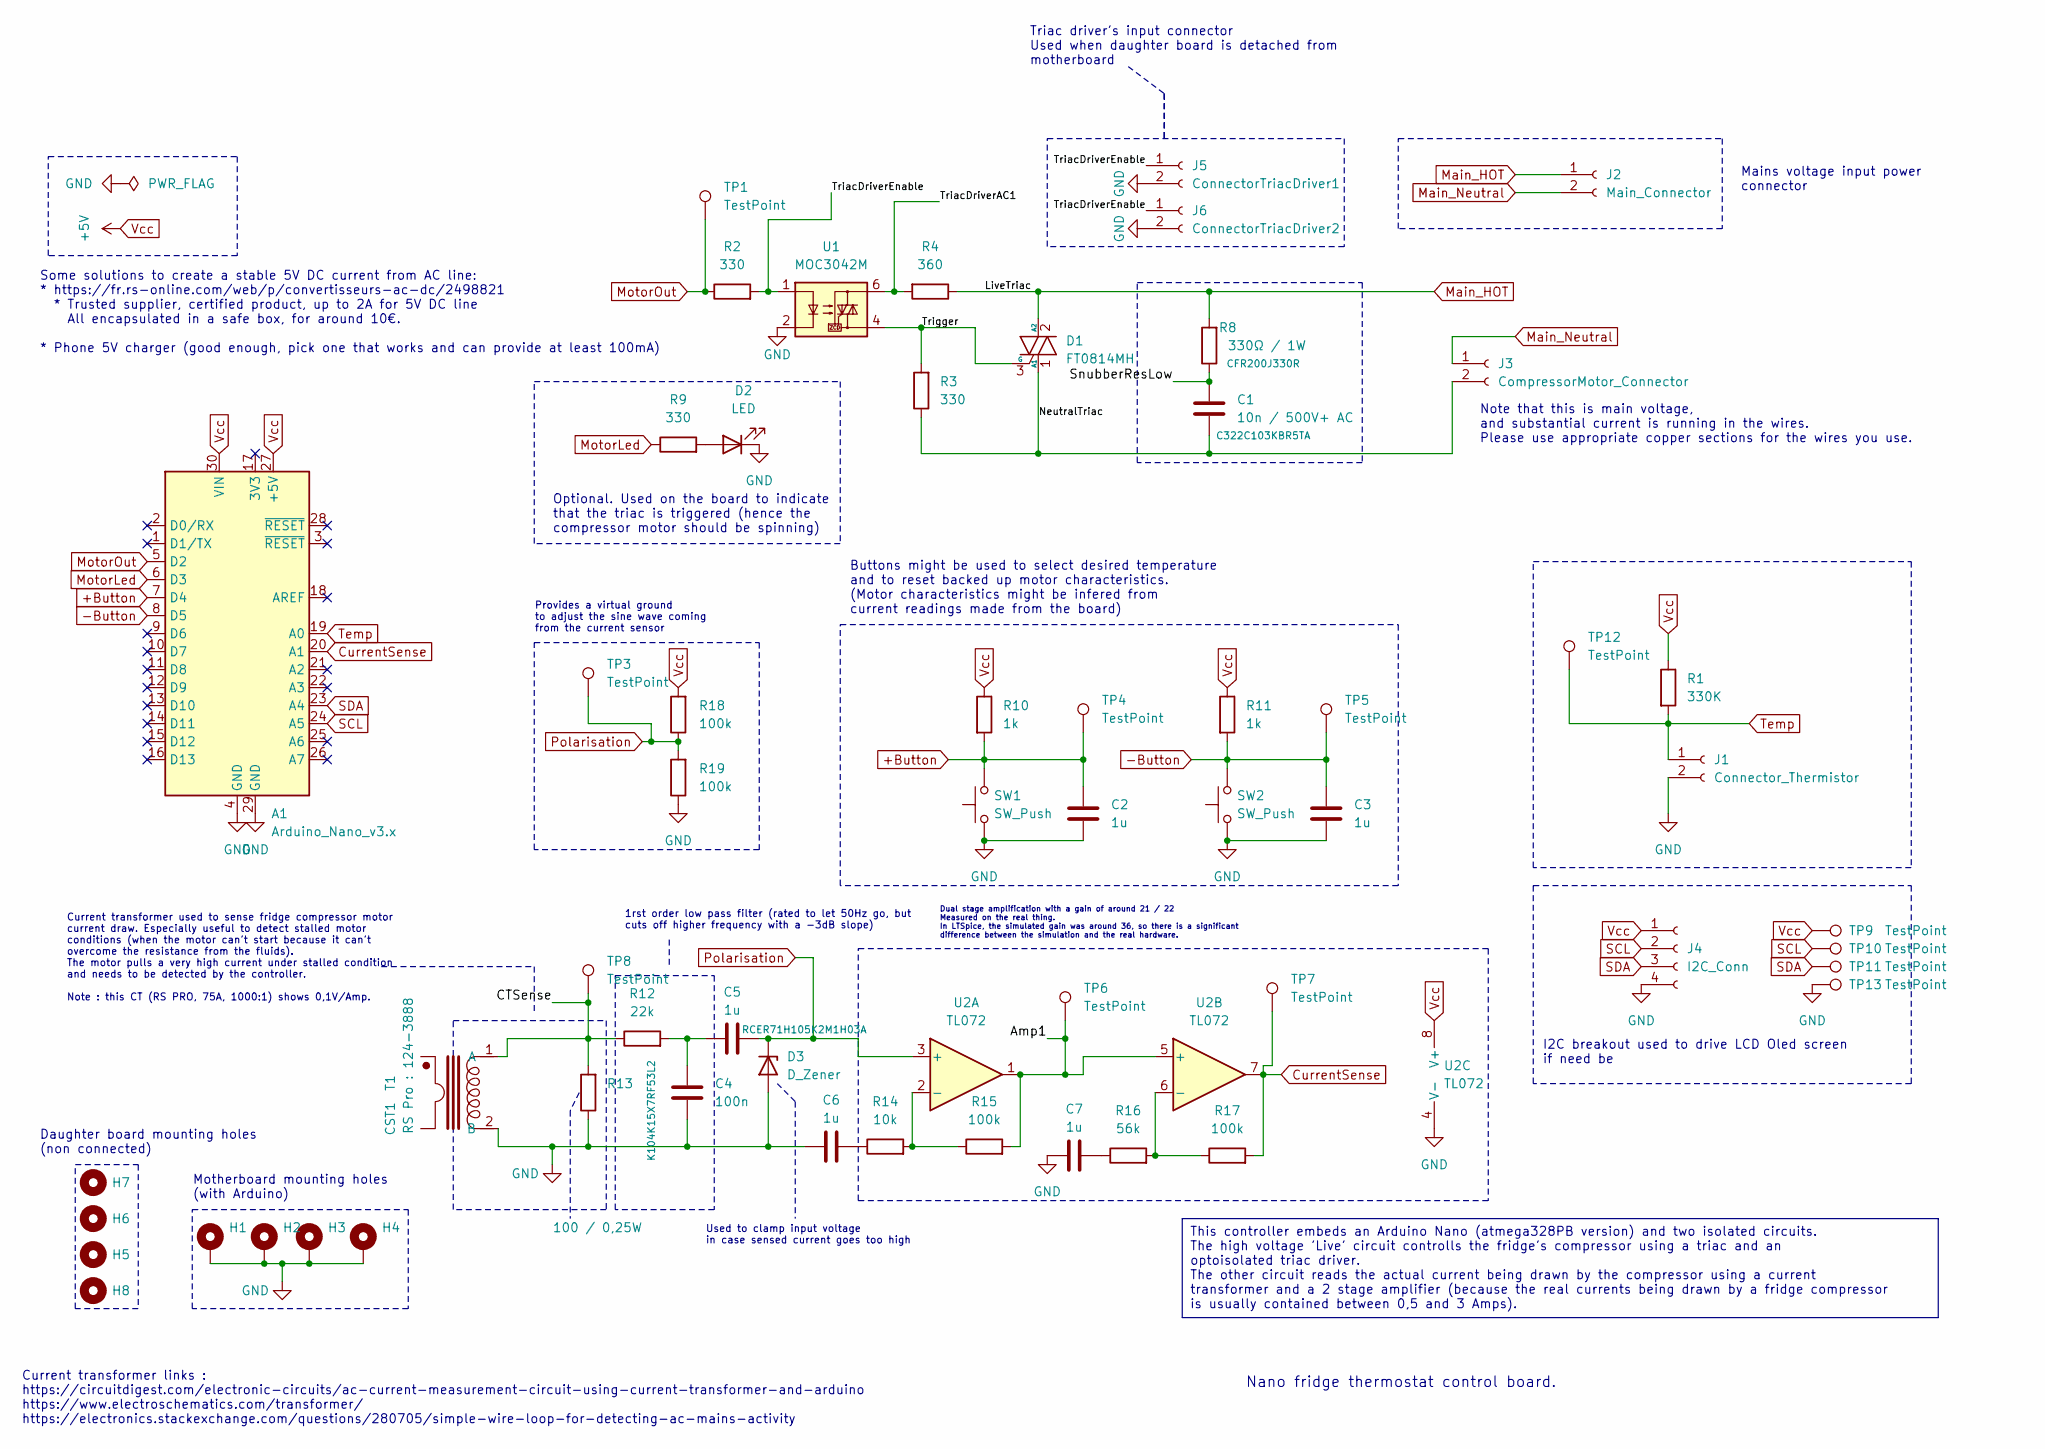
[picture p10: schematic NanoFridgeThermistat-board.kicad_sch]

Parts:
A1: Arduino_Nano_v3.x; Arduino_Nano
C1: 10n / 500V+ AC; C_Disc_D10.0mm_W2.5mm_P5.00mm
C2, C3, C5, C6, C7: 1u; C_Disc_D4.7mm_W2.5mm_P5.00mm
C4: 100n; C_Disc_D3.8mm_W2.6mm_P2.50mm
D1: FT0814MH; TO-220-3_Vertical
D2: LED; LED_D3.0mm
D3: D_Zener; D_DO-35_SOD27_P7.62mm_Horizontal
H1, H2, H3, H4: MountingHole_Pad; MountingHole_2.2mm_M2_DIN965_Pad
H5, H6, H7, H8: MountingHole; MountingHole_2.2mm_M2_ISO7380
J1: Connector_Thermistor; PinSocket_1x02_P2.54mm_Vertical
J2: Main_Connector; TE-282836-2-5.08mm
J3: CompressorMotor_Connector; TE-282836-2-5.08mm
J4: I2C_Conn; PinSocket_1x04_P2.54mm_Vertical
J5: ConnectorTriacDriver1; PinSocket_1x02_P2.54mm_Vertical
J6: ConnectorTriacDriver2; PinSocket_1x02_P2.54mm_Vertical
R1: 330K; R_Axial_DIN0207_L6.3mm_D2.5mm_P10.16mm_Horizontal
R2, R3, R9: 330; R_Axial_DIN0207_L6.3mm_D2.5mm_P10.16mm_Horizontal
R4: 360; R_Axial_DIN0207_L6.3mm_D2.5mm_P10.16mm_Horizontal
R8: 330Ω / 1W; R_Axial_DIN0614_L14.3mm_D5.7mm_P20.32mm_Horizontal
R10, R11: 1k; R_Axial_DIN0207_L6.3mm_D2.5mm_P10.16mm_Horizontal
R12: 22k; R_Axial_DIN0207_L6.3mm_D2.5mm_P10.16mm_Horizontal
R13: 100 / 0,25W; R_Axial_DIN0207_L6.3mm_D2.5mm_P10.16mm_Horizontal
R14: 10k; R_Axial_DIN0207_L6.3mm_D2.5mm_P10.16mm_Horizontal
R15, R17, R18, R19: 100k; R_Axial_DIN0207_L6.3mm_D2.5mm_P10.16mm_Horizontal
R16: 56k; R_Axial_DIN0207_L6.3mm_D2.5mm_P10.16mm_Horizontal
SW1, SW2: SW_Push; SW_PUSH_6mm
T1: CST1; CT-RSPRO-1243888
TP1, TP3, TP4, TP5, TP6, TP7, TP8, TP9, TP10, TP11, TP12, TP13: TestPoint; TestPoint_Pad_D1.0mm
U1: MOC3042M; DIP-6_W7.62mm
U2: TL072; DIP-8_W7.62mm

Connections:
+Button: A1.7 (D4), C2.1, R10.2, SW1.2, TP4.1
-Button: A1.8 (D5), C3.1, R11.2, SW2.2, TP5.1
/Amp1: R15.2, TP6.1, U2.1, U2.5 (+)
/CTSense: R12.1, R13.2, T1.1 (A), TP8.1
/NeutralTriac: C1.2, D1.1 (A1), J3.2, R3.1
/SnubberResLow: C1.1, R8.1
/TriacDriverAC1: R4.2, U1.6
/TriacDriverEnable: J5.1, J6.1, R2.2, U1.1
/Trigger: D1.3 (G), R3.2, U1.4
CurrentSense: A1.20 (A1), R17.2, TP7.1, U2.7
GND: A1.4 (GND), A1.29 (GND), C2.2, C3.2, C4.2, C6.1, C7.1, D2.1 (K), D3.2 (A), H1.1, H2.1, H3.1, H4.1, J1.2, J4.4, J5.2, J6.2, R13.1, R19.1, SW1.1, SW2.1, T1.2 (B), TP13.1, U1.2, U2.4 (V-)
Main_HOT: D1.2 (A2), J2.1, R4.1, R8.2
Main_Neutral: J2.2, J3.1
MotorLed: A1.6 (D3), R9.1
MotorOut: A1.5 (D2), R2.1, TP1.1
unnamed: C4.1, C5.1, R12.2
unnamed: C6.2, R14.1
unnamed: C7.2, R16.1
unnamed: D2.2 (A), R9.2
unnamed: R14.2, R15.1, U2.2 (-)
unnamed: R16.2, R17.1, U2.6 (-)
Polarisation: C5.2, D3.1 (K), R18.1, R19.2, TP3.1, U2.3 (+)
SCL: A1.24 (A5), J4.2, TP10.1
SDA: A1.23 (A4), J4.3, TP11.1
Temp: A1.19 (A0), J1.1, R1.2, TP12.1
Vcc: A1.27 (+5V), A1.30 (VIN), J4.1, R1.1, R10.1, R11.1, R18.2, TP9.1, U2.8 (V+)

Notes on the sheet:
This controller embeds an Arduino Nano (atmega328PB version) and two isolated circuits. The high voltage 'Live' circuit controlls the fridge's compressor using a triac and an optoisolated triac driver. The other circuit reads the actual current being drawn by the compressor using a current transfor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
Current transformer used to sense fridge compressor motor current draw. Especially useful to detect stalled motor conditions (when the motor can't start because it can't overcome the resistance from the fluids). The motor pulls a very high current under stalled condition and needs to be detected by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
Dual stage amplification with a gain of around 21 / 22 Measured on the real thing. In LTSpice, the simulated gain was around 36, so there is a significant difference between the simulation and the real hardware.
Triac driver's input connector Used when daughter board is detached from motherboard
Note that this is main voltage, and substantial current is running in the wires. Please use appropriate copper sections for the wires you use.
Provides a virtual ground to adjust the sine wave coming from the current sensor
Nano fridge thermostat control board.
1rst order low pass filter (rated to let 50Hz go, but cuts off higher frequency with a -3dB slope)
Daughter board mounting holes (non connected)
Optional. Used on the board to indicate that the triac is triggered (hence the compressor motor should be spinning)
Some solutions to create a stable 5V DC current from AC line: * https://fr.rs-online.com/web/p/convertisseurs-ac-dc/2498821 * Trusted supplier, certified product, up to 2A for 5V DC line All encapsulated in a safe box, for around 10€. * Phone 5V charger (good enough, pick one that works and can pro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
Buttons might be used to select desired temperature and to reset backed up motor characteristics. (Motor characteristics might be infered from current readings made from the board)
Motherboard mounting holes (with Arduino)
Mains voltage input power connector
I2C breakout used to drive LCD Oled screen if need be
Used to clamp input voltage in case sensed current goes too high
Current transformer links : https://circuitdigest.com/electronic-circuits/ac-current-measurement-circuit-using-current-transformer-and-arduino https://www.electroschematics.com/transformer/ https://electronics.stackexchange.com/questions/280705/simple-wire-loop-for-detecting-ac-mains-activity

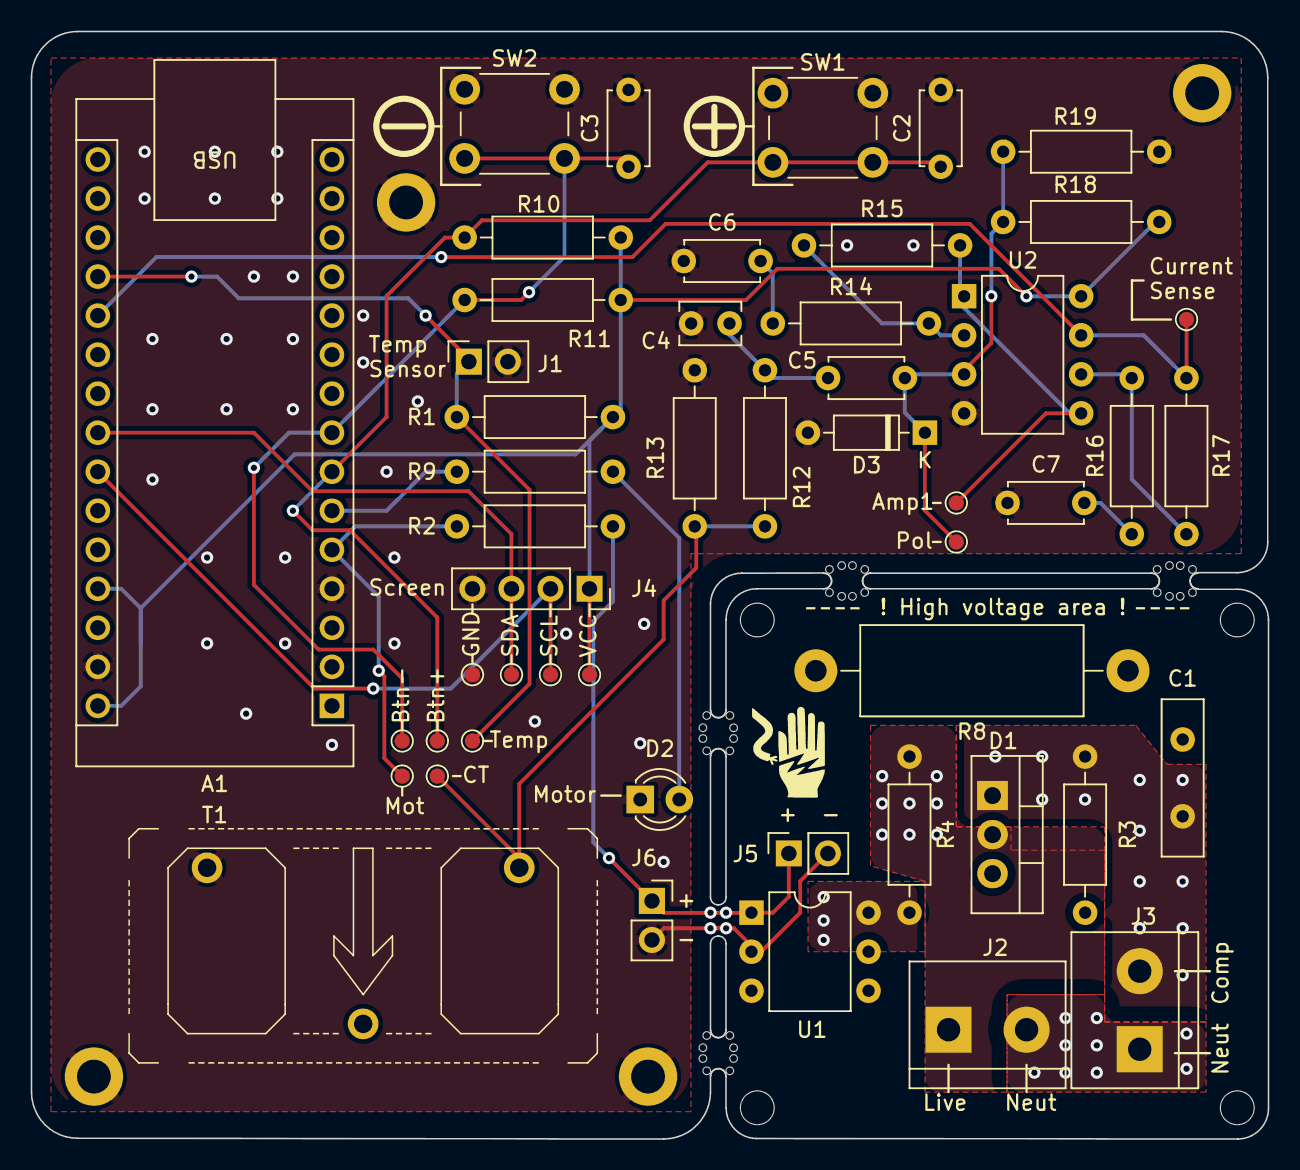
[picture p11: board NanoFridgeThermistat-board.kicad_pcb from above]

Board: 2 copper layers, 80.5 x 72.1 mm, 62 parts (0 on the bottom side), 26 nets.

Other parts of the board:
mouse-bite-1mm-slot, mouse-bite-1mm-slot#2, mouse-bite-1mm-slot#3, mouse-bite-1mm-slot#4: VAL**; mouse-bite-1mm-slot

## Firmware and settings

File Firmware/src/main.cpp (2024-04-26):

#include <Arduino.h>
#include <stdbool.h>
#include <stdint.h>

#include "Core/bridge.h"
#include "Core/buffers.h"
#include "Core/buttons.h"
#include "Core/current.h"
#include "Core/mcu_time.h"
#include "Core/thermistor.h"
#include "Core/thermistor_ntc_100k_3950K.h"

#include "Core/led.h"

#include "Hal/persistent_memory.h"
#include "Hal/timebase.h"

// clang-format off
// -> Clang has troubles treating multiline macros comments
// https://github.com/llvm/llvm-project/issues/54399


// ################################################################################################################################################
// ################################################### Read-only data & configs ###################################################################
// ################################################################################################################################################

// Permanent storage header and footer are used to make sure EEPROM was already
// used and is valid. These are default constant values which is really
// unlikely we'll find in the EEPROM straight from factory. They will be used
// to invalidate cached values and trigger board auto-learning
#define PERMANENT_STORAGE_HEADER 0xDE
#define PERMANENT_STORAGE_FOOTER 0xAD


#define SAMPLES_PER_SINE  20U   /**> How many samples we are using to depict a full sine wave.                           */
                                /**> Appropriate values might range from 10 to 20                                        */

#define STALLED_CURRENT_MULTIPLIER_PERCENT 20U /**> Used to detect overcurrent conditions.                               */
                                               /**> Inrush current is several times bigger than normal current           */

#define STEADY_MOTOR_RUNTIME 5U  /**> Minimum time to wait after motor is triggered to consider it in                    */
                                 /**> it's normal operation mode                                                         */

#define STALLED_MOTOR_WAIT_MINUTES 5U                                  /**> How long we'll need to wait between motor starts when motor is stalled  */
#define STALLED_MOTOR_WAIT_SECONDS (STALLED_MOTOR_WAIT_MINUTES * 60U)  /**> Same as above in seconds                                                */
#define STALLED_MOTOR_IMMUNE_PERIOD_AFTER_RESTART 10U                  /**> How long (in seconds) we prevent over current detection after a restart */

#define MAINS_AC_FREQUENCY_HZ 50U           /**> Mains outlet AC frequency (50 Hz in France)                            */

#define CURRENT_SENSOR_CHECK_RATE_HZ uint16_t(SAMPLES_PER_SINE * MAINS_AC_FREQUENCY_HZ)    /**> Current sensor check rate (frequency) - Hz               */

// Compiles down to constant anyway !
#define CURRENT_SENSOR_CHECK_PERIOD_MS uint8_t(1000 / CURRENT_SENSOR_CHECK_RATE)        /**> Current sensor check time period in milliseconds (between 2 sensor reads) */
#define CURRENT_SENSE_DC_BIAS_MV 2390

#define TEMP_HYSTERESIS_HIGH 2U     /**> Upper limit of the hysteresis window. If temp gets higher than 2°C above the target temp, we start the compressor  */
#define TEMP_HYSTERESIS_LOW 2U      /**> Lower limit of the hysteresis window. If temp gets lower than 2°C below the target temp, we stop the compressor    */


// ################################################################################################################################################
// ################################################### Debugging defines and flags ################################################################
// ################################################################################################################################################


#define DEBUG_SERIAL
#define DEBUG_TEMP 0
//#define DEBUG_CURRENT_RMS
//#define DEBUG_CURRENT_VOLTAGE

//#define CURRENT_LED_DEBUG
#define DEBUG_REPORT_PERIODIC 1
#if DEBUG_REPORT_PERIODIC == 1
    #define DEBUG_REPORT_PERIOD_SECONDS 1U
    #define DEBUG_REPORT_PERIOD_SECONDS_MOTOR_RESTART_ETA 10U
#endif
#define FORCE_OVERWRITE_EEPROM 0

#ifdef DEBUG_SERIAL
    #define MSG_LENGTH 50U
    char msg[MSG_LENGTH] = {0};
    #define LOG_INIT() Serial.begin(9600)
    #define LOG(msg) Serial.print(msg)
    #define LOG_CUSTOM(format, ...)                     \
        snprintf(msg, MSG_LENGTH, format, __VA_ARGS__); \
        LOG(msg);
#else
    #define LOG_INIT()
    #define LOG(msg)
    #define LOG_CUSTOM(format, ...)
#endif

// clang-format on

// ################################################################################################################################################
// ########################################################## Other Constants #####################################################################
// ################################################################################################################################################

// Pin mapping
const uint8_t motor_control_pin = 2; // D2
const uint8_t status_led_pin    = 3; // D3 -> PORTD3 of the atmega328PB Mcu
const uint8_t minus_button_pin  = 4; // D4
const uint8_t plus_button_pin   = 5; // D5

const uint8_t  temp_sensor_pin    = A0;    /**> NTC thermistor temperature sensor input pin             */
const uint8_t  current_sensor_pin = A1;    /**> Current sens input pin, sampled @ 500Hz - 1kHz          */
const uint16_t upper_resistance   = 330U;  /**> 320 kOhms resistor is used as the upper bridge resistor */
const uint16_t vcc_mv             = 5000U; /**> Board is powered via USB -> 5V                          */

const uint8_t led_driver_index = 0U;

// ################################################################################################################################################
// ################################################### Application state machine ##################################################################
// ################################################################################################################################################

/**
 * @brief controls the application state (state machine)
 */
typedef enum
{
    APP_STATE_NORMAL,             /**> Normal fridge operation                                                                                  */
    APP_STATE_POST_BOOT_WAIT,     /**> Post boot time window waits for 5 seconds without triggering the compressor.
                                       This allows the user to enter the Learning mode when exiting the boot.                                   */
    APP_STATE_MOTOR_STALLED,      /**> Motor stalled condition was detected, waiting for 5 minutes before trying again                          */
    APP_STATE_WAITING_START_MOTOR /**> We are waiting before restarting the motor. This is done before we run into the MOTOR STALLED condition  */
} app_state_t;

typedef struct
{
    app_state_t app_state; /**> Tracks application current state                                               */
    /**
     * @brief maps the start time conditions in a union
     * (because we are only using one value at a time, they are mutually exclusive)
     */
    union
    {
        uint32_t stalled_cond_time;  /**> Keeps track of the stalled condition start in time */
        uint32_t motor_start_time;   /**> Keeps track of the time where motor was started    */
        uint32_t motor_stopped_time; /**> Keeps track of the time where motor was shut off  */
    } tracking;

    /**
     * @brief Keeps track of button events (either Pressed, Released, or Hold)
     */
    struct
    {
        button_state_t plus_event;      /**> Plus button event                                                                                   */
        button_state_t prev_plus_event; /**> Used to detect the change in button event (detecting from Pressed to Hold and from Hold to Release) */

        // We need to detect transistion from the PRESSED event to the HOLD event exactly once
        button_state_t minus_event;      /**> Minus button event                                                                                  */
        button_state_t prev_minus_event; /**> Used to detect the change in button event (detecting from Pressed to Hold and from Hold to Release) */
    } buttons;

} app_working_mem_t;

typedef struct
{
    int8_t   temperature;
    uint16_t current_ma;
    uint16_t current_rms;
} app_sensors_t;

// Default configuration initialisation
static persistent_config_t config = {
    .header             = PERMANENT_STORAGE_HEADER,
    .target_temperature = 4,
    .current_threshold  = 500,
    .footer             = PERMANENT_STORAGE_FOOTER,
};

static led_io_t leds[1U] = {{.port = &PORTD, .pin = status_led_pin}};

// ################################################################################################################################################
// ####################################################### Static declarations ####################################################################
// ################################################################################################################################################

static void read_buttons_events(button_state_t* const plus_button_event, button_state_t* const minus_button_event, const mcu_time_t* time);
static void handle_normal_operation_loop(app_working_mem_t* const app_mem, int16_t const* const current_rms, const int8_t temperature,
                                         const mcu_time_t* time);
static void set_motor_output(const uint8_t value);
static bool is_motor_started(void);
static void read_temperature(const mcu_time_t* time, int8_t* temperature);

#ifndef NO_CURRENT_MONITORING
static app_state_t handle_motor_stalled_loop(uint32_t const* const start_time, const mcu_time_t* time);
static void        read_current(const mcu_time_t* time, int16_t* current_ma, int16_t* current_rms_ma);
#endif

#ifdef DEBUG_CURRENT_VOLTAGE
static circular_buffer_t voltage_buffer;
#endif

void setup()
{
    pinMode(minus_button_pin, INPUT);
    pinMode(plus_button_pin, INPUT);
    pinMode(motor_control_pin, OUTPUT);
    pinMode(status_led_pin, OUTPUT);
    pinMode(temp_sensor_pin, INPUT);
    pinMode(current_sensor_pin, INPUT);

    timebase_init();

    LOG_INIT();

    if (FORCE_OVERWRITE_EEPROM || persistent_mem_is_first_boot(PERMANENT_STORAGE_HEADER, PERMANENT_STORAGE_FOOTER))
    {
        LOG("Detected first boot condition, writing default config to EEPROM.\n");
        // Writes the default config on first boot so that it's a known starting
        // point for subsequent eeprom references.
        persistent_mem_write_config(&config);
        persistent_mem_read_config(&config);
    }
    else
    {
        LOG("Reading config from EEPROM.\n");
        // Otherwise, read back config from EEPROM
        persistent_mem_read_config(&config);
        LOG_CUSTOM("Read target temp in config : %d°C\n", config.target_temperature)
        LOG_CUSTOM("Read current threshold in config : %umA\n", (unsigned int)config.current_threshold)
    }

    led_init(leds, 1U);
    // led_set_blink_pattern(led_driver_index, LED_BLINK_NONE);
    sei();

#ifdef DEBUG_CURRENT_VOLTAGE
    circular_buffer_init(&voltage_buffer, 0);
#endif
}

void loop()
{
    static const mcu_time_t* time        = NULL;
    static int8_t            temperature = 0;
    static int16_t           current_ma  = 0;

#ifdef DEBUG_REPORT_PERIODIC
    static mcu_time_t previous_time;
#endif

    // Keeps track of the previous time the system was toggled
    static app_working_mem_t app_mem = {
        .app_state = APP_STATE_POST_BOOT_WAIT,
        .tracking  = {.motor_start_time = 0},
        .buttons =
            {
                .plus_event       = BUTTON_STATE_RELEASED,
                .prev_plus_event  = BUTTON_STATE_RELEASED,
                .minus_event      = BUTTON_STATE_RELEASED,
                .prev_minus_event = BUTTON_STATE_RELEASED,
            }, // Trailing comma is used to work around clang-format issues with struct fields initialization formatting
    };

    int16_t current_rms    = 0;
    bool    config_changed = false;

    // Very important to process the current time as fast as we can (polling mode)
    timebase_process();
    time = timebase_get_time();
    led_process(time);

#ifndef NO_CURRENT_MONITORING
    // Current is read at around 1kHz
    read_current(time, &current_ma, &current_rms);
#endif
    // Temperature is read once every 2 seconds
    read_temperature(time, &temperature);

    // Process button events.
    // Used to trigger
    read_buttons_events(&app_mem.buttons.plus_event, &app_mem.buttons.minus_event, time);

    // User pressed and release the + button.
    // Raise temp set point by one degree
    if (app_mem.buttons.plus_event == BUTTON_STATE_RELEASED && app_mem.buttons.prev_plus_event != app_mem.buttons.plus_event
        && app_mem.buttons.prev_plus_event != BUTTON_STATE_HOLD)
    {
        config.target_temperature++;
        LOG("Button + Clicked !\n");

        // Clamp max temperature to max of NTC curve
        if (config.target_temperature > thermistor_ntc_100k_3950K_data.data[thermistor_ntc_100k_3950K_data.sample_count - 1U].temperature)
        {
            config.target_temperature = thermistor_ntc_100k_3950K_data.data[thermistor_ntc_100k_3950K_data.sample_count - 1U].temperature;
        }
        config_changed = true;
        LOG_CUSTOM("-> New temp : %hd °C\n", config.target_temperature);
    }

    // User pressed and release the - button.
    // Reduce temp set point by one degree
    if (app_mem.buttons.minus_event == BUTTON_STATE_RELEASED && app_mem.buttons.prev_minus_event != app_mem.buttons.minus_event
        && app_mem.buttons.prev_minus_event != BUTTON_STATE_HOLD)

    {
        LOG("Button - Clicked !\n");
        config.target_temperature--;

        // Clamp max temperature to min of NTC curve
        if (config.target_temperature < thermistor_ntc_100k_3950K_data.data[0U].temperature)
        {
            config.target_temperature = thermistor_ntc_100k_3950K_data.data[0U].temperature;
        }
        config_changed = true;
        LOG_CUSTOM("-> New temp : %hd °C\n", config.target_temperature);
    }

    // Only update persistent configuration if it has changed (reduces the amount of writes)
    if (config_changed)
    {
        LOG("Writing configuration to EEPROM\n");
        persistent_mem_write_config(&config);
    }

    switch (app_mem.app_state)
    {
#ifndef NO_CURRENT_MONITORING
        case APP_STATE_MOTOR_STALLED: {
            app_mem.app_state = handle_motor_stalled_loop(&app_mem.tracking.stalled_cond_time, time);
            break;
        }
#endif

        case APP_STATE_POST_BOOT_WAIT:
        case APP_STATE_NORMAL:
        case APP_STATE_WAITING_START_MOTOR:
        default: {
            handle_normal_operation_loop(&app_mem, &current_rms, temperature, time);
            break;
        }
    }

    // Update previous buttons states
    app_mem.buttons.prev_minus_event = app_mem.buttons.minus_event;
    app_mem.buttons.prev_plus_event  = app_mem.buttons.plus_event;

#if DEBUG_REPORT_PERIODIC == 1
    if ((time->seconds - previous_time.seconds) > DEBUG_REPORT_PERIOD_SECONDS)
    {
        // Report few things about current states
        previous_time = *time;
        LOG_CUSTOM("temperature : %hd °C\n", temperature);
        LOG_CUSTOM("current : %hd mA\n", current_ma);
        LOG_CUSTOM("current RMS: %hd mA\n", current_rms);
        LOG_CUSTOM("config.target_temperature : %hd °C\n", config.target_temperature);
        LOG_CUSTOM("config.current_threshold : %hu mA\n\n", config.current_threshold);

#ifdef DEBUG_RMS_CURRENT
        // DEBUG RMS current calculation
        static int16_t rms_data[CURRENT_MEASURE_SAMPLES_PER_SINE] = {0};
        current_export_internal_data(&rms_data);
        for (uint8_t i = 0; i < CURRENT_MEASURE_SAMPLES_PER_SINE; i++)
        {
            LOG_CUSTOM("RMS data [%hu] = %hd\n", i, rms_data[i]);
        }
#endif

#ifdef DEBUG_CURRENT_VOLTAGE
        for (uint8_t i = 0; i < CURRENT_MEASURE_SAMPLES_PER_SINE; i++)
        {
            LOG_CUSTOM("Voltage/current data (mv) [%hu] = %hd\n", i, voltage_buffer.data[i]);
        }
#endif
    }
#endif
}

static void read_buttons_events(button_state_t* const plus_button_event, button_state_t* const minus_button_event, const mcu_time_t* time)
{
    static button_local_mem_t plus_button_mem = {
        .current  = LOW,
        .previous = LOW,
        .pressed  = 0,
        .event    = BUTTON_STATE_RELEASED,
    };
    static button_local_mem_t minus_button_mem = {
        .current  = LOW,
        .previous = LOW,
        .pressed  = 0,
        .event    = BUTTON_STATE_RELEASED,
    };

    plus_button_mem.current  = digitalRead(plus_button_pin);
    minus_button_mem.current = digitalRead(minus_button_pin);

    read_single_button_event(&plus_button_mem, &time->seconds);
    read_single_button_event(&minus_button_mem, &time->seconds);

    *plus_button_event  = plus_button_mem.event;
    *minus_button_event = minus_button_mem.event;
}

#ifndef NO_CURRENT_MONITORING
static app_state_t handle_motor_stalled_loop(uint32_t const* const start_time, const mcu_time_t* time)
{
    // Wait for 5 minutes before exiting this state
    uint32_t elapsed_time = time->seconds - *start_time;
    if (elapsed_time >= STALLED_MOTOR_WAIT_SECONDS)
    {
        LOG("Motor stalled timeout condition reached -> Reverting to normal mode.\n");
        // Revert to normal operation mode
        return APP_STATE_NORMAL;
    }
    return APP_STATE_MOTOR_STALLED;
}
#endif

static void handle_normal_operation_loop(app_working_mem_t* const app_mem, int16_t const* const current_rms, const int8_t temperature,
                                         const mcu_time_t* time)
{
    // Only trigger this event once, at first detection of the button
    // HOLD event, not the subsequent ones.

    // clang-format off
    if ((BUTTON_STATE_HOLD == app_mem->buttons.minus_event)
    && (app_mem->buttons.prev_minus_event != app_mem->buttons.minus_event))
    // clang-format on
    {
        LOG("Button - hold condition detected : Reverting current threshold to default.\n");
        // Reset memory back to default (starts a new "Learning" mode)
        config.current_threshold = 0;
        persistent_mem_write_config(&config);
        led_set_blink_pattern(led_driver_index, LED_BLINK_ACCEPT);

        led_next_event_t event = {.kind = LED_NEXT_EVENT_PATTERN, .data = {.pattern = LED_BLINK_BREATHING}};
        led_set_next_event(led_driver_index, &event);

        if (is_motor_started())
        {
            // Reset the tracker so that we start counting from now on
            app_mem->tracking.motor_start_time = time->seconds;
        }
    }

    // Just learnt new "normal" motor behavior ! Save it to persistent memory
    bool motor_run_long_enough = (time->seconds - app_mem->tracking.motor_start_time) > STEADY_MOTOR_RUNTIME;
    if (is_motor_started() && (config.current_threshold == 0) && (motor_run_long_enough))
    {
        config.current_threshold = *current_rms;
        led_set_blink_pattern(led_driver_index, LED_BLINK_ACCEPT);
        led_next_event_t event = {.kind = LED_NEXT_EVENT_IO_STATE, .data = {.io_state = (uint8_t)HIGH}};
        led_set_next_event(led_driver_index, &event);

        persistent_mem_write_config(&config);
        LOG("Learnt new basis current for normal operation ; Saving to EEPROM\n");
        LOG_CUSTOM("Current : %u, threshold : %u\n", *current_rms, config.current_threshold)
    }

#ifndef NO_CURRENT_MONITORING
    // Detected stalled motor, stop trying to trigger the compressor for now
    bool overcurrent_detected = *current_rms > (int16_t)(((100 + STALLED_CURRENT_MULTIPLIER_PERCENT) * config.current_threshold) / 100);

    // Wait for about 10 seconds to allow the motor to get back up to speed
    // clang-format off
    if ((config.current_threshold > 0)
    &&  (overcurrent_detected)
    &&  (time->seconds - app_mem->tracking.motor_stopped_time >= STALLED_MOTOR_IMMUNE_PERIOD_AFTER_RESTART))
    // clang-format on
    {
        LOG("Overcurrent detected, motor is probably stalled. Waiting for pressure to equalize in heat pump circuit.\n");
        app_mem->app_state = APP_STATE_MOTOR_STALLED;
        set_motor_output(LOW);
        app_mem->tracking.stalled_cond_time = time->seconds;

        led_set_blink_pattern(led_driver_index, LED_BLINK_WARNING);
        return;
    }
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

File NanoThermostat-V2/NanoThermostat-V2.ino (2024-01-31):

#include <stdint.h>
#include <stdbool.h>

#include "thermistor/thermistor.h"
#include "thermistor/thermistor_ntc_100k_3950K.h"

//#define F_CPU 16000000

const uint8_t  button_pin = 4; // D4
const uint8_t  relay_pin_1 = A4;
const uint8_t  relay_pin_2 = A5;

// Used to count ticks 100 times a second
volatile uint8_t timer_ticker = 0;


const uint16_t time_on_seconds = 3600;
const uint16_t time_off_seconds = 7200;

// Using TIMER2 CompA vector to increment the time variable
ISR(TIMER2_COMPA_vect)
{
  timer_ticker++;
}

/**
  * @brief Setups timer 2 as a slow timer (with the biggest prescaler of 1024) and sets the compare value so that the interrupt frequency is around 100Hz.
*/
void setup_timer(void)
{
  TCCR2A = (1 << WGM21); // CTC mode

  // Prescaler of 1024
  TCCR2B = (1 << CS22) | (1 << CS21) | (1<<CS20);

  // 16MHz / 1024 -> 15625 HZ
  // 15625 / 156 ~= 100,1 HZ -> closest to 100 Hz so we can just "count" up to 100 with a software counter and derive seconds out of this
  // 15625 / 157 ~= 99,5 HZ

  // Will raise an interrupt around 100 times per second
  OCR2A = 155;

  // Enable interrupts for this counter
  TIMSK2 |= (1<<OCIE2A);
  TCNT2 = 0;
}

void setup()
{
  pinMode(button_pin, INPUT_PULLUP);
  pinMode(relay_pin_1, OUTPUT);
  pinMode(relay_pin_2, OUTPUT);

  digitalWrite(relay_pin_1, LOW);
  digitalWrite(relay_pin_2, LOW);

  setup_timer();
  sei();
  //Serial.begin(9600);
}



// When the button is pushed, it means the refrigerator is in its "forced mode"
static bool forced_run = false;
static bool cooling_down = true;

// Keeps track of the previous time the system was toggled
static uint32_t previous_toggle = 0;

// Keeps track of current time
static uint32_t current_seconds = 0;

void aggregate_seconds(volatile uint8_t* ticker, uint32_t* seconds)
{
  if(*ticker >= 100)
  {
    *ticker = 0;
    (*seconds)++;
  }
}


void loop() {
  // read the state of the pushbutton value:
  forced_run = digitalRead(button_pin) == HIGH;

  aggregate_seconds(&timer_ticker, &current_seconds);

  //Serial.println(forced_run);

  // check if the pushbutton is pressed. If it is, the buttonState is HIGH:
  if (forced_run == true)
  {
    // turn LED on:
    digitalWrite(relay_pin_1, LOW);
    digitalWrite(relay_pin_2, LOW);
  }
  else
  {
    if((cooling_down)
    && (current_seconds - previous_toggle) >= time_on_seconds)
    {
      // Toggling cooling mode
      cooling_down = false;
      previous_toggle = current_seconds;
    }
    else if((!cooling_down
          && (current_seconds - previous_toggle) >= time_off_seconds))
    {
      cooling_down = true;
      previous_toggle = current_seconds;
    }

    if(cooling_down)
    {
      digitalWrite(relay_pin_1, LOW);
      digitalWrite(relay_pin_2, LOW);
    }
    else
    {
      digitalWrite(relay_pin_1, HIGH);
      digitalWrite(relay_pin_2, HIGH);
    }
  }
}

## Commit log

2023-11-28 Added simple arduino project, using very basic timer features
2023-12-15 Moved sketch so that it pleases Arduino Ide
2023-12-15 Added NTC calculus & characterization spreadsheet
    [Thermistor values.ods]
2023-12-15 reworked file and folder structure to split from version 1 to version 2
    [Thermistor values.ods]
2024-01-22 Added prototype for thermistors source files
2024-01-22 Added python source file generator for thermistors
2024-01-23 Added resistor bridge calculator script
2024-01-25 Fixing thermistor_generator data count
2024-01-26 Implemented and tested thermistor code
2024-01-26 Improved thermistor generator
2024-01-28 Added hardware layout with board
    [NanoFridgeThermistat-board.kicad_pcb, NanoFridgeThermistat-board.kicad_sch]
2024-01-28 Improved routing for hardware
    [NanoFridgeThermistat-board.kicad_pcb, NanoFridgeThermistat-board.kicad_sch]
2024-01-29 Added resistor bridge sources
2024-01-30 Added one more bridge resistor test
2024-02-06 Added platformio to ease Arduino developments with real project structure
2024-02-06 Added AC current sensing sim file with LTSpice (dual stage op amp)
2024-02-06 Added buttons and starting current sensor addition
    [NanoFridgeThermistat-board.kicad_sch]
2024-02-06 Added current transformers selection spreadsheet
    [CurrentTransformersSelection.ods]
2024-02-06 Added current sense hardware layout
    [NanoFridgeThermistat-board.kicad_sch]
2024-02-06 Added more parts sourcing
    [Components.ods, NanoFridgeThermistat-board.kicad_pcb, NanoFridgeThermistat-board.kicad_sch]
2024-02-06 Upgraded board with new models, components and layout
    [Components.ods, NanoFridgeThermistat-board.kicad_pcb, NanoFridgeThermistat-board.kicad_sch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]
2024-02-06 Updated spreadsheets
    [Components.ods, CurrentTransformersSelection.ods]
2024-02-06 Removed unused components
    [RS-PRO 1243888 Current Transformer-Body.stl]
2024-02-06 Changed base color of the board
    [NanoFridgeThermistat-board.kicad_pcb]
2024-02-06 Fixed last issues with DRC on PCB router
    [NanoFridgeThermistat-board.kicad_pcb]
2024-02-06 Adding mounting holes and test points
    [NanoFridgeThermistat-board.kicad_pcb, NanoFridgeThermistat-board.kicad_sch]
2024-02-06 Finalized board with testing points and mouse bites to detach AC board
    [BOM.ods, NanoFridgeThermistat-board.kicad_pcb, NanoFridgeThermistat-board.kicad_sch]
2024-02-06 Added mother-daughter boards connector on mother board as well
    [NanoFridgeThermistat-board.kicad_pcb, NanoFridgeThermistat-board.kicad_sch]
2024-02-07 moved Panelization footprint and tidied Spreadsheets
    [Components.ods, CurrentTransformersSelection.ods]
2024-02-07 Generated Gerbers files
    [BOM.ods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]
2024-02-07 Added drill files
    [NanoFridgeThermistat-board-NPTH.drl, NanoFridgeThermistat-board-PTH.drl]
2024-02-07 Added Open Source Hardware logo to boards
    [NanoFridgeThermistat-board.kicad_pcb]
2024-02-07 Updated documentation, added screenshots
    [BOM.ods]
2024-02-07 Exported board assembly as 3D step files
    [RS-PRO 1243888 Current Transformer-Body.step, TE-Connectivity-282836-2-C-282836-2.step, board-V2.0.0-assembly.FCStd]
2024-02-09 Removed V1 and renamed codebase to Firmware folder
    [Thermistor values.ods]
2024-02-11 Wiring things up
2024-02-14 Reworked timebase to also count milliseconds (to allow 500-1Kz operations)
    [main.cpp]
2024-02-14 Added throttled analog reads, sensors are not read at every turn of the loop
2024-02-15 Used button events to change temperature set point
2024-02-19 Adding basic temperature control + reformats
2024-02-22 Added current module test -> RMS calculation
2024-02-22 Improved a little bit current module with arbitrary RMS calculation
2024-02-23 WIP : LED driver + time refactor
2024-02-23 WIP Led implementation
2024-02-26 Refactored a bit led config and implemented led on/off in breathing mode
2024-02-27 Added led_tests
2024-02-27 Implemented and tested led accept pattern
2024-03-06 First upload to the board with blinking LED
2024-03-08 Added Serial prints (optional) and fixed Bridge implem (data overflows)
    [led.h, main.cpp]
2024-03-08 Added a Spanner (distribution) algorithm to spread data evenly in a sequence
    * Spanner algorithm distributes data evenly in a given data sequence
    * Useful to implement LED Pulse density modulation when frequency is
    around 100 Hz
    * Will be used to dim the LED smoothly (virtual resolution of 100 steps,
    10ms actuation max)
2024-03-08 Improved LED system, pulse stuffing is not adapted for this purpose. Higher frequency is.
2024-03-08 harware : swapped misplaced buttons
    [NanoFridgeThermistat-board.kicad_pcb]
2024-03-08 Improved ON time of the LED by centering values lower
2024-03-13 Implemented lots of debug serial and fixed all functional aspects
    [led.c, led.h, main.cpp]
2024-03-13 Trying to have a good current reading
2024-03-13 Fixed Header and Footer EEPROM reads
    [main.cpp]
2024-03-15 Added time guards before running the motor after a stop
    * Changed motor cycling conditions to avoid running in Stalled condition
    when we don't wait enough time
    * This happens if the temperature sensor sees fast temperature
    variations oscillating in and out the hysteresis window.
    * Prevents the motor to start if it was shut down less than 5 minutes
    ago
    [main.cpp]
2024-03-15 Improved motor start wait period when we've just booted
2024-04-17 Updated codebase toward better current sensing
2024-04-17 Updated KiCad project files
    [102 RESISTOR PACK010.fcstd, 189 RESISTOR PACK010.fcstd, ACProtection.step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]
2024-04-19 Improved current measurements and fixed timing issues ; now RMS is good
    [NanoFridgeThermistat-board.kicad_sch]
2024-04-19 Enabled an immune period after stalled motor condition to allow the motor to get back up to speed
    [current.h, main.cpp]
2024-04-19 Added measured currents spreadsheet
    [ACCurrentsReadouts.ods]
2024-04-19 Added capability to set the LED state when falling back to NONE pattern
2024-04-26 Added NO_CURRENT_MONITORING control define which removes the need for a current detector

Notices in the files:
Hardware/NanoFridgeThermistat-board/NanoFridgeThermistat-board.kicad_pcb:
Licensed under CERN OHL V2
